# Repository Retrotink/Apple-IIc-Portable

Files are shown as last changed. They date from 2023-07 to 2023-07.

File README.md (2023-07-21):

# Apple-IIc-Portable
Add-on Screen and Battery turns your Apple IIc into a portable computer













The primary compenents are right off of Amazon and modified to fit into a case. 

# Power Source
<br>
The battery power source is a $39.99 12000mAh battery pack that has been removed from its original case and modified so that a new
switch replaces the original. The charging circuit is modified so that when plugged in it is charging but no power comes out
until the new add-on switch is turned on. The original design would apply power all the time. 
<br>
This method gives us control of when we can turn on the entire computer and monitor with one switch. 
The Apple IIc power switch is left on covered by the new power connector that goes up into the battery circuit.
While this seems complex, the modification gives us the functionality to power the computer properly.
When plugged in, power is drawn from battery while also charging. 
<br>
Original Battery pack on Amazon:<br>

https://www.amazon.com/gp/product/B00ME3ZH7C/ref=ox_sc_saved_image_10?smid=A24OIV2F0TL1K3&psc=1<br>

power source

<br>
DIN Connector:<br>
https://www.amazon.com/gp/product/B07XCSX3JP/ref=ox_sc_saved_image_6?smid=A13GGF3VKVFGBN&psc=1<br>

din

<br>
The hinge uses a stainless steel M4 rod that was cut to size and 2 nuts and washers were sourced from Home Depot.<br>
https://www.amazon.com/gp/product/B08SC7QD3V/ref=ox_sc_saved_image_7?smid=A4SNXMCYCTCYM&psc=1
<br>

rods

<br>
The 2.1mm power connector is a Mouser.com part 502-721A<br>

power2 1

<br>
The power switch is a Mouser.com part 629-GRS-4021-0001<br>

rocker

<br>

# The LCD Monitor
<br>

lcd

<br>
The LCD monitor is a $73 Hikity 10 inch LCD that runs on 12V and has VGA, BNC, composite and HDMI inputs. <br>
https://www.amazon.com/gp/product/B077FSR36B/ref=ox_sc_saved_title_9?smid=AZV2Q3JGU683F&psc=1<br>
It was programmed in 4:3 mode and the the LCD and driver board was removed from the original case.<br>
The button panel was disconnected from the driver board and set aside. It is not currently installed.<br>
The 3D PLA Plastic design carefully covers the monitor so that on power up, none of the boot graphics from the monitor appear.<br>
The VGA, BNC and HDMI connectors were removed by desoldering. The 12V connector was retained for easy conntion to the battery circuit.<br>
<br>

# Cables
<br>
A DB15 cable to composite runs up from that back of the Apple IIc, under the battery container and up into the LCD Panel.<br>
Power for the monitor does not come from the DB15 Video port but directly from the power supply board.<br>
The Power DIN connector runs up into the battery and connects to the battery circuit.<br>
A new switch in the power supply turns on both the computer and the monitor with one single throw of the switch<br>
<br>

# The 3D printed Case
<br>
For the 3D objects a Creality CR10S Pro V2 was used as the printer. It has a glass bed for good adhesion and objects are printed upright.<br>
The PLA FilaCube $23.97 and is pretty close in color to a retrobright Apple IIc.<br>
https://www.amazon.com/gp/product/B076Z26NS5/ref=ox_sc_saved_title_1?smid=AFZQIF3WLZ4BA&psc=1<br>
<br>

pla

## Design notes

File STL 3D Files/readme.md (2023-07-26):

These are the individual STL files <br>
<br>
On Tinkercad you can search for:<br>
Apple IIc Portable V6.8

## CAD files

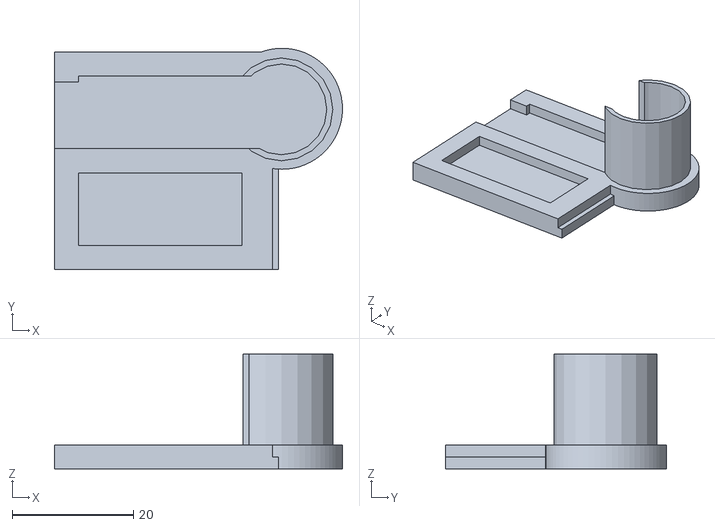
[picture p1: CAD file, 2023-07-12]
STL 3D Files/IIc power V6.8.stl
47.6 x 36.6 x 19.0

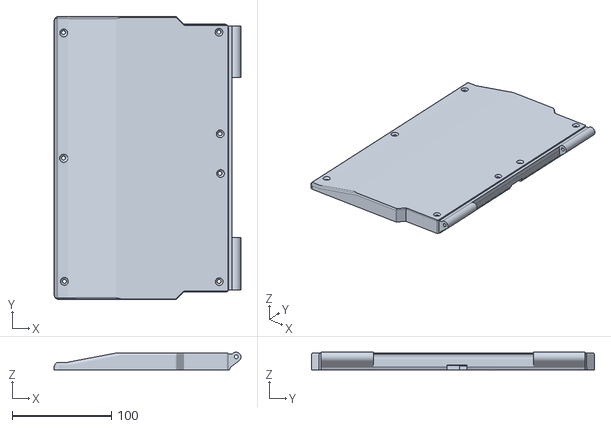
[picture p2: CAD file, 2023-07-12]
STL 3D Files/IIc LCD Back V6.8.stl
188.7 x 286.1 x 18.0

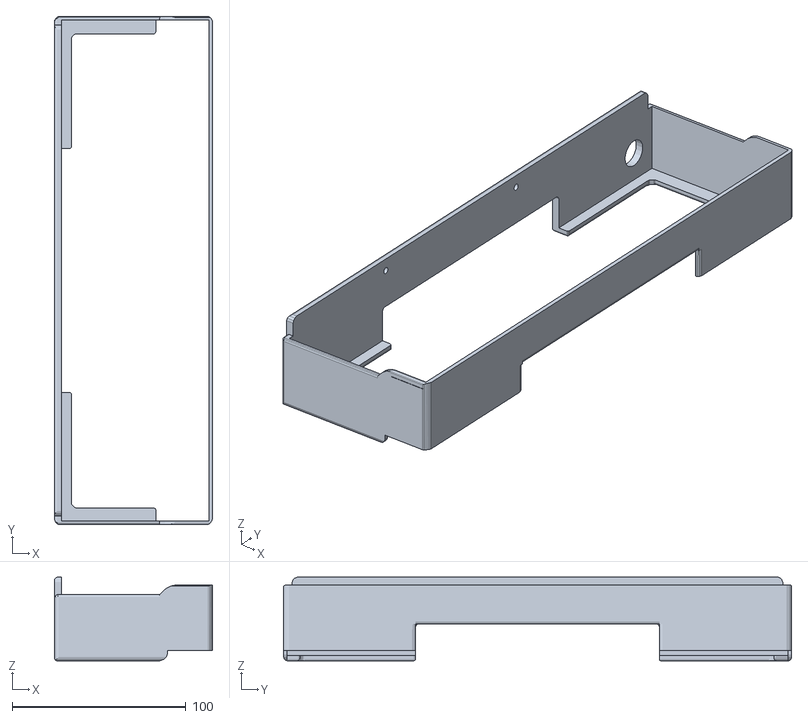
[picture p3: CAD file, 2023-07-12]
STL 3D Files/IIc Belt V6.8.stl
91.0 x 292.0 x 48.0

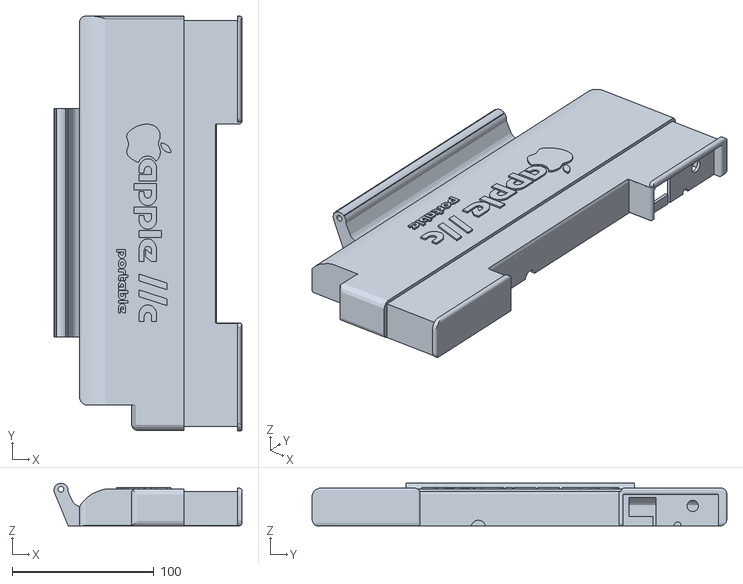
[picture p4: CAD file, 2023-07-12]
STL 3D Files/IIc battery 6.8.stl
132.4 x 292.0 x 30.0

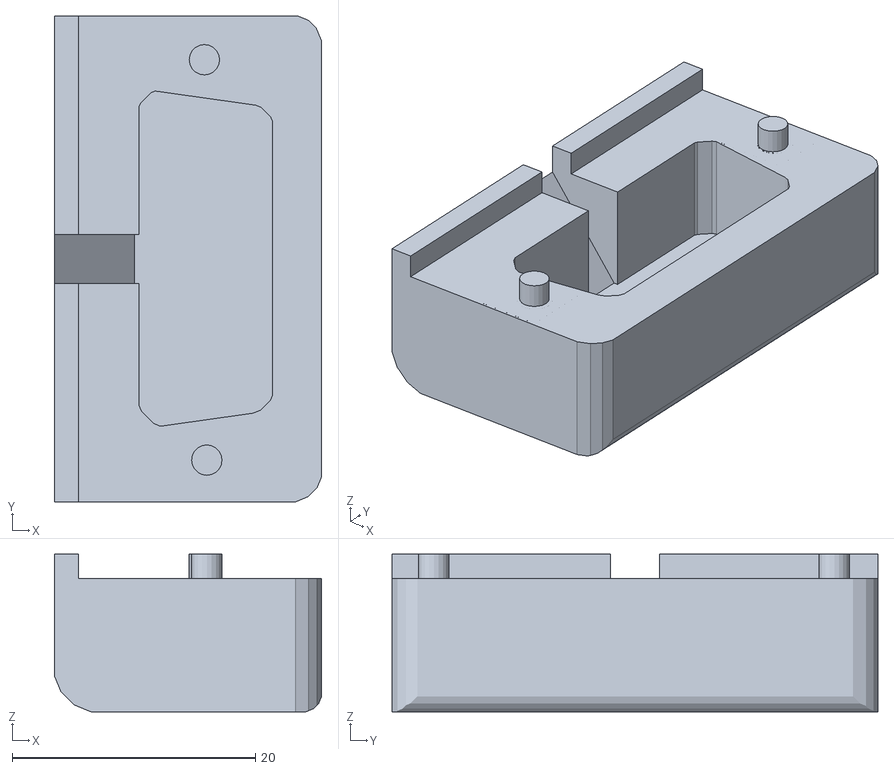
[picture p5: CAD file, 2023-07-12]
STL 3D Files/IIc Video V6.8.stl
22.0 x 40.0 x 13.0

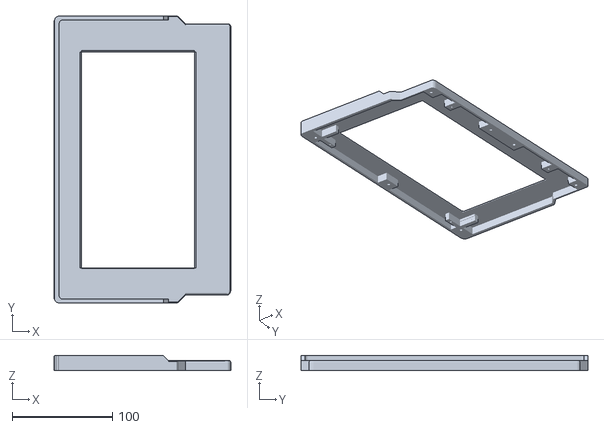
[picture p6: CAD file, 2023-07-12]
STL 3D Files/IIc LCD Bezel V6.8.stl
176.0 x 286.0 x 15.0

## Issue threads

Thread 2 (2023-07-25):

Cad files available?

a2retro, 2023-07-25:
Hi What was the CAD program you used and will you be adding the source files to the repo?
Thanks for sharing your work.

Retrotink, 2023-07-25:
The STL Files are the CAD files for making the case.

ibytergj, 2023-07-25:
STL files are good for printing but not that great for making modifications. Would it be possible to upload STEP files?

Retrotink, 2023-07-26:
Sorry, I only have STL files. All pieces were created on Tinkercad

a2retro, 2023-07-26:
Okay, thanks for checking. I will fork and see if I can find a way to convert to STEP

a2retro, 2023-07-26:
I opened in TinkerCAD and saw there was an option to send to Fusion360. Trying that now. I use Eagle/Fusion360 for my cards designs so this might work out well.

Retrotink, 2023-07-26:
Ok, maybe it is just too much for 1, I can split up the pieces in Tinkercad and see if that helps?

a2retro, 2023-07-26:
I think it has something to do with only primitive shapes can be passed to Fusion. Looking into alternatives to convert from STL. There’s nothing wrong with tinkercad per se it’s just that I’d rather not have to try and learn yet another program. 🙂

ibytergj, 2023-07-27:
Just a FYI, the power and video covers converted to Fusion solids nicely. The battery, belt and LCD front bezel converted with a few issues. Needs additional work to fix the missing parts and combine some sections to make a cleaner model in Fusion. I have not been able to get a solid model from the LCD back bezel yet. Will keep you updated on progress.

Closed 2023-10-29.

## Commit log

2023-06-29 Create STL Files for 3D printers
2023-07-12 stl files
